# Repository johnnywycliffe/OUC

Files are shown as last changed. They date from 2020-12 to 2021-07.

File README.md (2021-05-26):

# Open Underglow Controller (OUC)
This project is designed to provide a better underglow control scheme than the one that comes with the LED strips. It has it's own controls, a small OLED screen, and a connector to the CANBUS for connecting to the car.

## Features
 - ESP 32 controller for fast LED updates
 - 256-bit colors for millions of colors
 - Configuarable patterns for uniqueness
 - Animations!
 - Brakes and turn signal controls for extended light modes
 - 4 12v channels to drive Underglow
 - 2 5v channels to drive extra underglow strips
 - CAN BUS connection to use LEDs as car gauges
 - Wifi/Bluetooth mode for phone control
 - Optional screen and joystick controls to bypass need for phone

## Hardware 
In this project are PCB files needed to order a board, parts files for having a board assembled, and 3d files for a 3d printing a case.

A full hardware list can be found in docs/hardware.md

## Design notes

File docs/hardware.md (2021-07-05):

# Hardware
Description of PCB and other hardware components needed 

## PCB Bill Of Materials
Prices are listed for 1 component as of 26MAY2021 from links provided

| Item Symbol | Part number | Usage | Quantity | Price (Unit) | Link |
| --- | --- | ----- | --- | --- | ---- |
| C1 | 100u (1210) | Decoupling | 1 | $0.19 | [Link](https://www.digikey.com/en/products/detail/cal-chip-electronics-inc/GMC32X5R107M6R3NT/12140448) |
| C2 | 1u (0402) | Decoupling | 1 | $<0.01 | [Link](https://www.digikey.com/en/products/detail/cal-chip-electronics-inc/GMC04X5R105K10NT/12324831) |
| C3, C4 | 2.2u (0603) | Decoupling | 2 | $<0.01 | [Link](https://www.digikey.com/en/products/detail/cal-chip-electronics-inc/GMC10X5R225K16NT/13908834) |
| C5 | 22n (0603) | Decoupling | 1 | $0.12 | [Link](https://www.digikey.com/en/products/detail/samsung-electro-mechanics/CL10B223KC8WPNC/11487758) |
| C6, C11, C12, C14 | 0.1u (0603) | Decoupling | 4 | $<0.01 | [Link](https://www.digikey.com/en/products/detail/cal-chip-electronics-inc/GMC10Y5V104Z16NTD/13907945) |
| C7, C8 | 47u (1210) | Decoupling | 2 | $<0.01 | [Link](https://www.digikey.com/en/products/detail/cal-chip-electronics-inc/GMC32X5R476M6R3NT/14288292) |
| C9, C10, C13, C15-20 | 10u (0603) | Decoupling | 9 | $0.02 | [Link](https://www.digikey.com/en/products/detail/cal-chip-electronics-inc/GMC10X5R106M6R3NT/13908308) |
| D1 | RB088BM-60TL | Reverse Polarity Protection | 1 | $1.01 | [Link](https://www.digikey.com/en/products/detail/rohm-semiconductor/RB088BM-60TL/13532505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) |
| D2 | TPSMA6L15A | TVS Diode | 1 | $0.43 | [Link](https://www.mouser.com/ProductDetail/Littelfuse/TPSMA6L15A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) |
| D3 | VSSAF512-M3/H | Switch mode power supply | 1 | $0.37 | [Link](https://www.mouser.com/ProductDetail/Vishay-General-Semiconductor/VSSAF512-M3-H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) |
| D4, D5 | TPSMB15A | CAN BUS ESD protection | 2 | $0.51 | [Link](https://www.mouser.com/ProductDetail/Littelfuse/TPSMB15A?qs=rXmh1mW8ce0d2DkAI15E9g%3D%3D) |
| D6 | B5818WS-F2-0000HF | USB reverse polarity protection | 1 | $0.03 | [Link](https://www.digikey.com/en/products/detail/yangzhou-yangjie-electronic-technology-co-ltd/B5818WS-F2-0000HF/13911526) |
| D7, D8 | 150040RS73240 | Indicator LEDs | 2 | $0.30 | [Link](https://www.digikey.com/en/products/detail/w%C3%BCrth-elektronik/150040RS73240/8557156) |
| F1 | 3413.0330.22 | Main fuse | 1 | $0.52 | [Link](https://www.digikey.com/en/products/detail/schurter-inc/3413-0330-22/2644179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) |
| J2 | 5063N17 | DB-9 connector for CANBUS | 1 | $2.08 | [Link](https://www.mcmaster.com/db9-connectors/computer-connection-type~db9/) |
| J3 | 47590-0001 | USB Connector | 1 | $0.74 | [Link](https://www.mouser.com/ProductDetail/Molex/47590-0001?qs=B2dI1vFk2x%252BDCUfk3sC4bA%3D%3D) |
| L1 | SRR1208-6R5ML | Inductor for Swich mode power supply | 1 | $1.01 | [Link](https://www.mouser.com/ProductDetail/Bourns/SRR1208-6R5ML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) |
| Q1, Q2 | SS8050-G | BJTs for boot mode | 2 | $0.26 | [Link](https://www.digikey.com/en/products/detail/comchip-technology/SS8050-G/6138901) |
| R1 | 49.9K (0603)  | Switch mode power supply | 1 | $<0.01 | [Link](https://www.digikey.com/en/products/detail/viking-tech/AR03DTC4992/12141691) |
| R2 | 100K (0603) | Switch mode power supply | 1 | $<0.01 | [Link](https://www.digikey.com/en/products/detail/viking-tech/CR-03FL7-100K/12141977) |
| R3 | 17.8K (0603) | Switch mode power supply | 1 | $<0.01 | [Link](https://www.digikey.com/en/products/detail/meritek/CR161782F/13405853) |
| R4, R5, R8, R10, R12, R14 | 10K (0603) | Various | 6 | $<0.01 | [Link](https://www.digikey.com/en/products/detail/viking-tech/CR-03FL7-10K/12141843) |
| R6 | 120 (0603) | CAN BUS Termination | 1 | $<0.01 | [Link](https://www.digikey.com/en/products/detail/meritek/CR16121J/13407570) |
| R7 | 4.7K (0603)  | USB Interface reset | 1 | $<0.01 | [Link](https://www.digikey.com/en/products/detail/meritek/CR16472J/13408047) |
| R9, R11, R13 | 27K (0603) | Voltage divider | 3 | $<0.01 | [Link](https://www.digikey.com/en/products/detail/meritek/CR16273J/13411248) |
| R15, R16 | 2.2k (0603) | LED Current limiting | 2 | $<0.01 | [Link](https://www.digikey.com/en/products/detail/meritek/CR16222J/13408118) |
| U1 | ESP-WROOM-32E (16MB) | Control device | 1 | $2.99 | [Link](https://www.mouser.com/ProductDetail/Espressif-Systems/ESP32-WROOM-32EM113EH2800PH3Q0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) |
| U2 | LMR14030-Q1 | 12-5v Switching regulator | 1 | $3.06 | [Link](https://www.mouser.com/ProductDetail/Texas-Instruments/LMR14030SQDDARQ1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) |
| U3 | NCP1117ST33T3G | 5-3.3v LDO | 1 | $0.56 | [Link](https://www.mouser.com/ProductDetail/ON-Semiconductor/NCP1117ST33T3G?qs=Gev%252BmEvV0iZb%2FE8ahUDx3w%3D%3D) |
| U4 | TXB0108DQSR | 3.3-5v Level shifter | 1 | $1.36 | [Link](https://www.digikey.com/en/products/detail/texas-instruments/TXB0108DQSR/2260592) |
| U5 | SN65HVD230 | CAN-bus Tranceiver | 1 | $3.00 | [Link](https://www.mouser.com/ProductDetail/Texas-Instruments/SN65HVD230QDRG4Q1?qs=pZC5fsuWujFPbC0sa1rjKA%3D%3D) |
| U6 | USBLC6-2SC6 | USB protection IC | 1 | $0.61 | [Link](https://www.mouser.com/ProductDetail/STMicroelectronics/USBLC6-2SC6?qs=po45yt2pPpu%2FhNIlwQdTlg%3D%3D) |
| U7 | CP2102N-A01-GQFN28 | USB Interface IC | 1 | $1.51 | [Link](https://www.mouser.com/ProductDetail/Silicon-Labs/CP2102N-A02-GQFN28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) |

## External electrical compentents
| Part name/number | Description | QTY | Price (unit) | Link |
| --- | --- | --- | ---| ---- |
| OBD2 Cable | Cable from OB2 Port of Car to device | 1 | $9.95 | [Link](https://www.digikey.com/catalog/en/partgroup/obd-ii-to-db9-cable/57744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,the%20cable%20is%20five%20feet.) |
| LEDS  WS2811, 12v | Some LEDs for test or install | 1 | $25.99 | [Link](https://www.amazon.com/BTF-LIGHTING-Addressable-Flexible-Silicone-Waterproof/dp/B01CNL6LLA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) |
| Joystick | Generic Joystick w/ pushbutton used for navigation of the menus | 1 | $1.00 | [Link](https://www.amazon.com/Wishiot-Joystick-Controller-Breakout-Arduino/dp/B089VXPHDH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) |
| OLED 0.96" | SSD1306, SPI screen for displaying information | 1 | $5.00 | [Link](https://www.amazon.com/CenryKay-0-96inch-Display-Compatible-Microcontroller/dp/B08238DZDL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) |
| Power interupt switch | Cut power to device to avoid draining battery | 1 | $5.79 | [Link](https://www.amazon.com/Baomain-Toggle-Switch-waterproof-cover/dp/B01IYD8SHQ) |
| Cable | Automotive grade cable with 3 cores | Varies | Varies | None |
| Cable connectors | Waterproof connectors, 5 core | 1-2 | $10.99 | [Link](https://www.amazon.com/gp/product/B01LCV8ZMA/ref=ppx_yo_dt_b_asin_title_o00_s00?ie=UTF8&psc=1)

## Case
TODO

## Pinout
Last verified on ver 1.3.2
| Item | Pin | Restrictions |
| ---- | --- | --- |
| LED SPARE 1 | 2 | No |
| LED Data (right) | 4 | No |
| LED Data (front) | 5 | No |
| OLED DC | 12 | No |
| OLED Reset | 14 | No |
| LED SPARE 2 | 15 | No |
| LED Data (rear) | 16 | No |
| LED Data (left) | 17 | No |
| OLED CLK | 18 | Hardware locked |
| SPI MISO | 19 | Hardware locked |
| Aux | 21 | Analog |
| Joystick Button | 22 | Needs internal pullup |
| SPI MOSI | 23 | Hardware locked |
| CAN TX | 25 | No |
| OLED CS | 26 | No |
| Brake Input | 32 | Input only | 
| CAN RX | 33 | No |
| Turn signal input Left | 34 | Input only |
| Turn Signal input Right | 35 | Input only | 
| Joystick X | 36 | Analog |
| Joystick Y | 39 | Analog |

## Notes
### Power
Vehicle power systems are generously described as "Hostile". So, there needs to be a system in place to get the power to everything. The voltage ranges from 11-14V and 10A typically, but there's spikes. Using a Trasient-Voltage-Suppression Diode, these problems are mitigatred.

12V is sent straight to LED strips via thick trace, an dimmediately regulated down to 5v, which is copper layer 3.

3.3v is moslty routed via layer 4, since it's spidering around the board.

### Misc
Screen D0 is CLK, D1 is MOSI.

Default QTY of Underglow LEDS is 18 for front and back, 30 for left and right.

Joystick is oriented with headers up.
- Y Axis pot is HIGH when DOWN, LOW when UP
- X Axis pot is HIGH when LEFT, LOW when RIGHT

May want to reorient for ease of mounting.

Pin 33 spazzes on software load.

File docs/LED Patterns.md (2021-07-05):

# LED Patterns
A list of patterns to implement.

Pixel order is clockwise, starting at front drivers corner front LED strip by default.

Use a pallette for storing colors. This allows for blending.

User defines up to four colors and the pallete adjusts for that

Special modes and effects are patterns, but don't utilize the data the same way.

Current test LEDS:
- Front/Back LED count is 18 pixels in groups of three
- Side LED count is 30 Pixels in groups of three.

## Math
To make sure the pattern loops around properly, move along length of palette like this:

paletteIndex = round(Current LED * (256/length of string))

This will minimized rounding error stackup. Example using pixel 55 of 96: 56 * 256/96 = 56 * 2.667 = 149.352 -> 149

Division is performed first to avoid overflowing.

## Patterns
Basic patterns, user programmable

1. 1 Wide: Two colors, odd pixels are color 1, evens color 2
2. 2 wide: every two pixels alternates color 1 and 2
3. 3 Wide: every three pixels...
4. 6 wide: every six pixels...
5. Dot(s) (with trail when animated)
6. Solid

## Animations
Can be applied to basic patterns

1. Cycle clockwise (Sawtooth?)
2. Cycle counterclockwise
3. Fade in and out
4. Fade in and out, alternating
5. Fade, random
6. Sinewave shift (Cylon)
7. Dot shift
8. Color pop - random color appears at random location. Spreads out until next pixel covers it up
9. Splatter - color(s) fades as it gets closer to back of vehicle
10. Drip - color(s) randomly, suddenly appears and fades

## Special patterns
Preset patterns, more complex than the "simple" patterns

1. Pacifica - Looks like water flowing 
2. Rising flames - Kind of like a candle
3. Twinklefox - Snow?
4. MURICA - Blue and white in the front, red and white down sides and rear. Flutters?
5. Valentine's - Pink, white and purple
6. Shamrock - Green shifting pattern
7. Halloween - Orange, green and purple
8. Christmas - Red and green lights, white twinkles
9. FFTss

## Colors
### Built in palettes
1. RainbowColors_p
2. RainbowStripeColors_p
3. OceanColors_p
4. CloudColors_p
5. LavaColors_p
6. ForestColors_p
7. PartyColors_p

### Pre-defined colors
1. Red
2. Green
3. Blue
4. White
5. Pink
6. Purple
8. Cyan
9. Yellow

More need added...

## Gauges
### Monochrome
1. Back to forwards (Front and back strips point inwards)
2. Forwards to back (Front and back strips point outwards)
3. Current gear (Brightness, color, or number of illuminated pixels)

### Multicolor
1. Back to forwards with "red" zone
2. Forwards to back with "red" zone
3. Layered gauges (Tracking two stats, overlaid)
4. Equalizer, with 'local maximum'

## Spare LEDs 1 & 2
These can either mimic the underglow, take only the primary color, or do something completely different.

## Turn signal and brake hardwires
### Brakes
1. Off
2. Off when not pressed, lit when pressed
3. Dim when not pressed, lit when pressed

### Turn signals
1. Off
2. Only sides of car, solid yellow
3. Sides of car in solid yellow, Outer front and rear LEDs flash yellow as well
4. Side of car in solid yellow, rear leds flash red on/off
5. Only sides of car, chasing yellow
6. Sides of car in chasing yellow, Outer front and rear LEDs flash yellow as well
7. Side of car in chasing yellow, rear leds flash red on/off

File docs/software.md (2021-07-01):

# Software
Software description and some constructs

## Overview
The general use of this device is to drive underglow LEDs based on a variety of inputs, with an extra few channels for additional LEDs should they be installed.

The inputs to the device are:
- OBD2/CANBUS: Direct information from the car. RPM, Throttle position, speed, gear, and anything else available.
- Self/Animations: Pre-programmed animations to drive LEDs in a set pattern.
- Turn Signals/Brakes: When installed, can light up red when braking and flash yellow when using turn signals

To choose between these, there is bluetooth mode or a joystick/button combo, or can be operated by computer

## Classes (make seperate libraries?)
- Menu: Handles operation ot he menu
  - Screen: Handles screen manipulation for menu class
  - Input: Handles joystick and button presses
  - Parser: Handles input from a serial device
    - Computer: Loads settings in ardiuno terminal when attached to a computer
    - Bluetooth: Loads data in when attached to bluetooth
- LEDPreset: Sets LEDs to be displayed
  - LEDPattern: Only contains data for an individual pattern
  - PatternManager: Actually updates patterns, inits them based on LEDPattern fed
  - LEDManager: Handles all hardware interface functions
- CAN: handle back and forth info to and from car
- EEPROM manager: Saving data to eeprom
- Settings: Settings stuff

## LED setup
- 5 presets saved to EEPROM, can be recalled at any time
- 1 Active preset; preset that will run when settings are finalized/aborted
- 1 preset for currently being modified patterns (called test)
- 1 LED manager
- 1 Pattern Manager

### Breakdown of LED operational theory
LEDManager:
- Has reference to real LEDs, all hardware driving functions
- Can call update function
- Shared between presets

LEDPreset:
- Generates pattern string with given preset
- Each preset has a pattern defined for each of the three strings: Underglow, Spare1 and Spare2
- These subpatterns are built into an overarching pattern which is loaded into LEDmanager

LEDPatterns:
- Where the current pattern is defined. Contains data like offset, length, brightness, palette...
- Does NOT contain LED array. Just information needed to construct array
- Probably could be a struct.

PatternManager:
- Given a LEDPattern, an offset and an Array to operate on, updates LEDs accordingly
- Shared between presets
- This class is going to setup and update the LEDs based on confiuration handed to it

## Menu
### Actives
- Load a new menu, resets sel and runs setupmenu(State)
- Load a new menu with a limited number of options
- Load a new menu with a custom title
- Save active pattern to test pattern
- Save test pattern to current pattern - abstract to two?
- Load a new menu and throw an eror for caution (Wiring, OBD-II, etc)
- Load a new menu and update selected LED string
- Save RGB order into hardware struct
- Save LED count into hardware struct
- Save LED flip state into hardware struct
- Save turn signal pattern into device settings
- Save brake pattern into device settings
- Save autoshutoff state into device settings
- Bluetooth

### Passives
- Update color palette on active: Active is known, state and sel describe 
- Update screen brightness: deviceSettings is known, 

# OUTDATED
Anything below this needs to be revised/removed

### Menu
The menu has a few modes:
- Navigation: consists of menu and submenues
- Choose color/pallete: Used to set colors
- Choose text: Used to set text (if needed)
- Choose PID: Choose a valid PID to monitor for gauges
- Variable adjust: Brightness, speed, anything represented as 1 number

LED patterns will continue to run while running settings.
- Custom patterns will change in real time for ease of modification
- Preset patterns will display when selecting them
- When choosing direction, indicate clockwise and have a slow clockwise pattern
- When choosing RGB, get initialization parameters and adjust accordingly. This may be difficult.
- When setting brakes and turn signals, provide a preview in real time

### OLED
A monochrome OLED display. Generic, used to display information about settings. 

### CAN/OBD2
The CAN/OBD2 libraries in use handle most of the packet send and receive pattern, only requiring a PID to get the relevant data in the correct units.

There are also helper functions to determine if a PID is valid, show units, and find all valid PIDs on a network.

### Input (Joystick)
Input is managed through a 2-axis joystick with 2 buttons. One of the buttons is part of the joystick.

### EEPROM
The EEPROM is used to store settings between power cycles.

There is a struct used to save and load all of the settings. It always writes the entire structure to the EEPROM, so limit number of times settings are saved. The struct uses put() and get() to avoid complicated byte management.

The same struct is what the rest of the program uses to get settings.

There is also a reset function.

### FastLED
See Patterns document for LED implementation.

## Settings
Some settings:
- Reverse direction of LED bar (For incorrect instals
- Set LED bar length
- Bluetooth on/of
- Bluetooth password (if possible)
- Blackout mode

## Bluetooth
Bluetooth integration can be done with no additional hardware, but will require a bunch of work on the software end, including a companion app for Android and iPhone.

Bluetooth works similarly to serial communication (read: it works identically from the ESP's perspective), but the messages have to be parsed on either end and displayed to the user in a sane manner. This is handled by the App for most bluetooth controllers on the market.

A standard for setting the LEDs needs to be made.

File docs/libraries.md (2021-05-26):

# Libraries
List of libraries used in the project and licenses needed to use them.

| Library Name | Author | Version | License | Link |
| --- | --- | --- | --- | ---- |
| Arduino-CAN | SandeepMistry | 0.3.1 | MIT | [Link](https://github.com/sandeepmistry/arduino-CAN) |
| Arduino-OBD2 | SandeepMistry | 0.0.0 | MIT | [Link](https://github.com/sandeepmistry/arduino-OBD2) |
| FastLED | Samguyer | 3.4.0 | MIT | [Link](https://github.com/FastLED/FastLED) |
| ESP 32 OLED | Thingpulse | 4.1.0 | MIT | [Link](https://github.com/ThingPulse/esp8266-oled-ssd1306) |
| Button | Michael Adams | 1.0.0 | MIT | [Link](https://github.com/madleech/Button) |

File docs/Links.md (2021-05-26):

# Links
## OBD2 info
[OBD2 explained](https://www.csselectronics.com/screen/page/simple-intro-obd2-explained/language/en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,that%20it%20can%20run%20on.)

[OBD2 PID list](https://en.wikipedia.org/wiki/OBD-II_PIDs)

[Send/receive info](https://happilyembedded.wordpress.com/2015/07/23/thirst-for-knowledge-sae-j1979-protocol/)

## ESP 32 info
[ESP 32 CAN (non-ardino)](http://www.iotsharing.com/2017/09/how-to-use-arduino-esp32-can-interface.html)

[ESP32 flash memory](https://www.electronics-lab.com/project/using-esp32s-flash-memory-for-data-storage/)

[ESP 32 based Logger board (for ref)](https://circuitmaker.com/Projects/Details/Craig-Peacock-4/OBD2-CAN-Logger)

[ESP 32 web portal](https://randomnerdtutorials.com/esp32-web-server-arduino-ide/)

[ESP 32 OBD2 Emulator](https://github.com/limiter121/esp32-obd2-emulator)

[Flash memory](https://randomnerdtutorials.com/esp32-flash-memory/)

[ESP WROOM 32 datasheet](https://www.espressif.com/sites/default/files/documentation/esp32-wroom-32e_esp32-wroom-32ue_datasheet_en.pdf)

[ESP32 Datasheet](https://www.espressif.com/sites/default/files/documentation/esp32_datasheet_en.pdf)

[ESP 32 Hardware design guidelines](https://www.espressif.com/sites/default/files/documentation/esp32_hardware_design_guidelines_en.pdf)

[ESP 32 Pinout](https://randomnerdtutorials.com/esp32-pinout-reference-gpios/)

## LEDS
[LED Library comparisons](https://blog.ja-ke.tech/2019/06/02/neopixel-performance.html)

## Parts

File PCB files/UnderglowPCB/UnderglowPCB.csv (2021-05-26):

Id | Designator | Quantity | Manufacturer | MFG Part # | Description/Value | Package | Type | Notes
1 | U1 | 1 | Espressif Systems | ESP32-WROOM-32E (M113EH2800PH3Q0) | Micrcontroller | ESP32-WROOM-32 | SMD
2 | D3 | 1 | Vishay General Semiconductor | VSSAF512-M3/H | Schottky diode | DO-221AC | SMD
3 | C1 | 1 | CAL-CHIP ELECTRONICS, INC. | GMC32X5R107M6R3NT | 100u | C_1210_3225Metric | SMD
4 | C12,C11,C14,C6 | 4 | CAL-CHIP ELECTRONICS, INC. | GMC10Y5V104Z16NTD | 0.1u | C_0603_1608Metric | SMD
5 | U4 | 1 | Texas Instruments | TXB0108DQSR | 3.3v to 5v Logic Level shifter | SON-20 | SMD
6 | U6 | 1 | Texas Instruments | SN65HVD230QDRG4Q1 | CAN-BUS Tranciever | SOIC-8 | SMD
7 | U8 | 1 | Sillicon Labs | CP2102N-A02-GQFN28 | USB to UART Bridge | QFN-28 | SMD
8 | D1 | 1 | ROHM Semiconductor | RB088BM-60TL | Schottky Protection diode | TO-252-2_TabPin1 | SMD
9 | C9,C17,C16,C15,C18,C19,C20,C13,C10 | 9 | CAL-CHIP ELECTRONICS, INC. | GMC10X5R106M6R3NT | 10u | C_0603_1608Metric | SMD
10 | D6 | 1 | Yangzhou Yangjie Electronic Technology Co.,Ltd | B5818WS-F2-0000HF | B5818WS | D_SOD-323 | SMD
11 | R7 | 1 | Meritek | CR16472J |  | R_0603_1608Metric | SMD
12 | U7 | 1 | STMicroelectronics | USBLC6-2SC6 | ESD Suppression | SOT-23-6 | SMD
13 | R8,R10,R12,R14,R4,R5 | 6 | Viking Tech | CR-03FL7---10K | 10k | R_0603_1608Metric | SMD
14 | J3 | 1 | Molex | 47590-0001 | USB_B_Micro | USB_Micro-AB_Molex_47590-0001 | Thru-hole
15 | F1 | 1 | Schurter Inc | 3413.0330.22 | Fuse | Fuse_1206_3216Metric | SMD
16 | U3 | 1 | ON Semiconductor | NCP1117ST33T3G | 3.3V Regulator | SOT-223-3_TabPin2 | SMD
17 | R9,R11,R13 | 3 | Meritek | CR16273J | 27k | R_0603_1608Metric | SMD
18 | R6 | 1 | Meritek | CR16121J | 120 | R_0603_1608Metric | SMD
19 | Q1,Q2 | 2 | Comchip Technology | SS8050-G | NPN Transistor | SOT-23 | SMD
20 | C2 | 1 | CAL-CHIP ELECTRONICS, INC. | GMC04X5R105K10NT | 1u | C_0402_1005Metric | SMD
21 | D7,D8 | 2 | Würth Elektronik | 150040RS73240 | LED | LED_0603_1608Metric | SMD
22 | R15,R16 | 2 | Meritek | CR16222J |  | R_0603_1608Metric | SMD
23 | C3,C4 | 2 | CAL-CHIP ELECTRONICS, INC. | GMC10X5R225K16NT | 2.2u | C_0603_1608Metric | SMD
24 | C5 | 1 | Samsung Electro-Mechanics | CL10B223KC8WPNC | 22n | C_0603_1608Metric | SMD
25 | C7,C8 | 2 | CAL-CHIP ELECTRONICS, INC. | GMC32X5R476M6R3NT | 47u | C_1210_3225Metric | SMD
26 | D2 | 1 | Littelfuse | TPSMA6L15A | TVS Diode | DO-221AC-2 (SMA) | SMD
27 | D4,D5 | 2 | Littelfuse | TPSMB15A | TPSMB15CA | DO-214AA-2 | SMD
28 | L1 | 1 | Bourns | SRR1208-6R5ML | 6.5u | Non-standard | SMD
29 | R1 | 1 | Viking Tech | AR03DTC4992 | 49.9k | R_0603_1608Metric | SMD
30 | R2 | 1 | Viking Tech | CR-03FL7--100K | 100k | R_0603_1608Metric | SMD
31 | R3 | 1 | Meritek | CR161782F | 17.8k | R_0603_1608Metric | SMD
32 | U2 | 1 | Texas Instruments | LMR14030SQDDARQ1 | 12v Switch mode power supply | 8-PowerSOIC (0.154", 3.90mm Width) | SMD
33 | J8,J9,J10,J4,J5,J6,J7,J1 | 8 |  |  | Conn_01x03 | PinHeader_1x03_P2.54mm_Vertical |  | DNS/DNP/DNI
34 | J11 | 1 |  |  | Conn_01x05 | Joystick_Header |  | DNS/DNP/DNI
35 | J12 | 1 |  |  | Conn_01x07 | SSD1306_Footprint |  | DNS/DNP/DNI
36 | J2 | 1 |  |  | DB9_Male | DB9 |  | DNS/DNP/DNI

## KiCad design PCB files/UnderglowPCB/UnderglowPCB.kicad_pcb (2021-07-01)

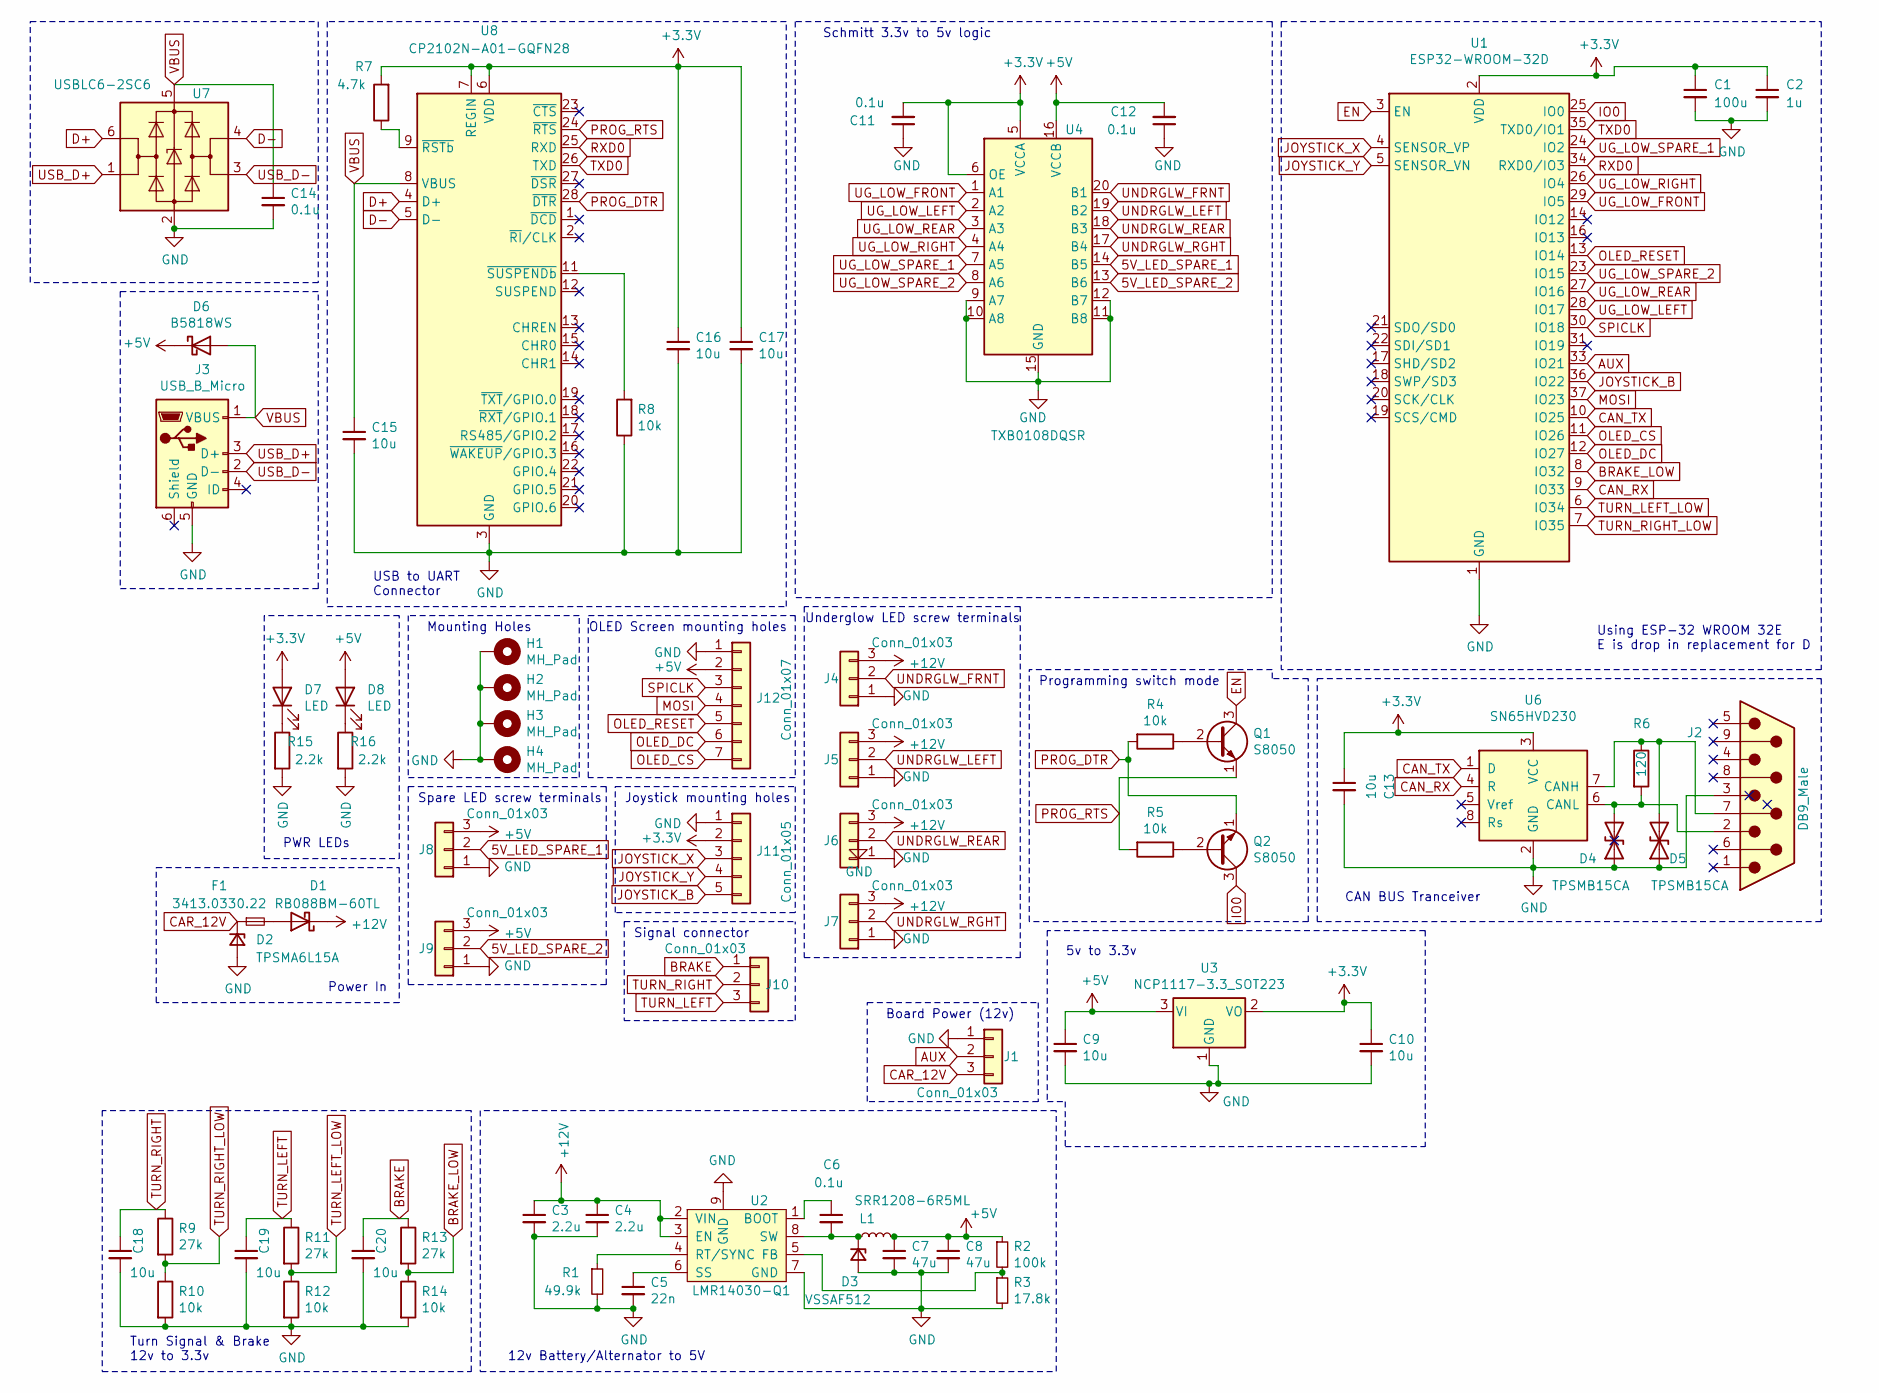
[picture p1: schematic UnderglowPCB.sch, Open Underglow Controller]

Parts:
C1: 100u; C_1210_3225Metric
C2: 1u; C_0402_1005Metric
C3, C4: 2.2u; C_0603_1608Metric
C5: 22n; C_0603_1608Metric
C6, C11, C12, C14: 0.1u; C_0603_1608Metric
C7, C8: 47u; C_1210_3225Metric
C9, C10, C13, C15, C16, C17, C18, C19, C20: 10u; C_0603_1608Metric
D1: RB088BM-60TL; TO-252-2_TabPin1
D2: TPSMA6L15A
D3: VSSAF512; DO-221AC
D4, D5: TPSMB15CA
D6: B5818WS; D_SOD-323
D7, D8: LED; LED_0603_1608Metric
F1: 3413.0330.22; Fuse_1206_3216Metric
H1, H2, H3, H4: MH_Pad; MountingHole_4.3mm_M4_Pad_Via
J1, J4, J5, J6, J7, J8, J9, J10: Conn_01x03; PinHeader_1x03_P2.54mm_Vertical
J2: DB9_Male; DB9
J3: USB_B_Micro; USB_Micro-AB_Molex_47590-0001
J11: Conn_01x05; Joystick_Header
J12: Conn_01x07; SSD1306_Footprint
L1: SRR1208-6R5ML; SRR1208
Q1, Q2: S8050; SOT-23
R1: 49.9k; R_0603_1608Metric
R2: 100k; R_0603_1608Metric
R3: 17.8k; R_0603_1608Metric
R4, R5, R8, R10, R12, R14: 10k; R_0603_1608Metric
R6: 120; R_0603_1608Metric
R7: 4.7k; R_0603_1608Metric
R9, R11, R13: 27k; R_0603_1608Metric
R15, R16: 2.2k; R_0603_1608Metric
U1: ESP32-WROOM-32D; ESP32-WROOM-32
U2: LMR14030-Q1; Texas_HSOP-8-1EP_3.9x4.9mm_P1.27mm_ThermalVias
U3: NCP1117-3.3_SOT223; SOT-223-3_TabPin2
U4: TXB0108DQSR; USON-20_2x4mm_P0.4mm
U6: SN65HVD230; Texas_HSOP-8-1EP_3.9x4.9mm_P1.27mm_ThermalVias
U7: USBLC6-2SC6; SOT-23-6
U8: CP2102N-A01-GQFN28; QFN-28-1EP_5x5mm_P0.5mm_EP3.35x3.35mm

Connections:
5V_LED_SPARE_1: J8.2, U4.14 (B5)
5V_LED_SPARE_2: J9.2, U4.13 (B6)
+3V3: C1.1, C2.1, C10.1, C11.2, C13.1, C16.1, C17.1, D7.2 (A), J11.2, R7.2, U1.2 (VDD), U3.2 (VO), U4.5 (VCCA), U4.6 (OE), U6.3 (VCC), U8.6 (VDD), U8.7 (REGIN)
+5V: C7.1, C8.1, C9.1, C12.2, D6.1 (K), D8.2 (A), J8.3, J9.3, J12.2, L1.2, R2.1, U3.3 (VI), U4.16 (VCCB)
+12V: C3.1, C4.1, D1.1 (K), J4.3, J5.3, J6.3, J7.3, U2.2 (VIN), U2.3 (EN)
AUX: J1.2, U1.33 (IO21)
BRAKE: C20.1, J10.1, R13.1
BRAKE_LOW: R13.2, R14.1, U1.8 (IO32)
CAN_RX: U1.9 (IO33), U6.4 (R)
CAN_TX: U1.10 (IO25), U6.1 (D)
CAR_12V: D2.1 (K), F1.1, J1.3
D+: U7.6 (I/O1), U8.4 (D+)
D-: U7.4 (I/O2), U8.5 (D-)
EN: Q1.3 (C), U1.3 (EN)
GND: C1.2, C2.2, C3.2, C4.2, C5.2, C7.2, C8.2, C9.2, C10.2, C11.1, C12.1, C13.2, C14.2, C15.2, C16.2, C17.2, C18.2, C19.2, C20.2, D2.2 (A), D3.2 (A), D4.1 (A1), D5.1 (A1), H1.1, H2.1, H3.1, H4.1, J1.1, J2.3, J3.5 (GND), J4.1, J5.1, J6.1, J7.1, J8.1, J9.1, J11.1, J12.1, R1.2, R3.2, R8.1, R10.2, R12.2, R14.2, R15.2, R16.2, U1.1 (GND), U1.15 (GND), U1.38 (GND), U1.39 (GND), U2.7 (GND), U2.9 (GND), U3.1 (GND), U4.9 (A7), U4.10 (A8), U4.11 (B8), U4.12 (B7), U4.15 (GND), U6.2 (GND), U7.2 (GND), U8.3 (GND), U8.29 (GND)
IO0: Q2.3 (C), U1.25 (IO0)
JOYSTICK_B: J11.5, U1.36 (IO22)
JOYSTICK_X: J11.3, U1.4 (SENSOR_VP)
JOYSTICK_Y: J11.4, U1.5 (SENSOR_VN)
MOSI: J12.4, U1.37 (IO23)
unnamed: C5.1, U2.6 (SS)
unnamed: C6.1, U2.1 (BOOT)
unnamed: C6.2, D3.1 (K), L1.1, U2.8 (SW)
unnamed: D1.2 (A), F1.2
unnamed: D4.2 (A2), J2.2, R6.2, U6.6 (CANL)
unnamed: D5.2 (A2), J2.7, R6.1, U6.7 (CANH)
unnamed: D7.1 (K), R15.1
unnamed: D8.1 (K), R16.1
unnamed: Q1.2 (B), R4.1
unnamed: Q2.2 (B), R5.1
unnamed: R1.1, U2.4 (RT/SYNC)
unnamed: R2.2, R3.1, U2.5 (FB)
unnamed: R7.1, U8.9 (~RSTb)
unnamed: R8.2, U8.11 (~SUSPENDb)
OLED_CS: J12.7, U1.11 (IO26)
OLED_DC: J12.6, U1.12 (IO27)
OLED_RESET: J12.5, U1.13 (IO14)
PROG_DTR: Q2.1 (E), R4.2, U8.28 (~DTR)
PROG_RTS: Q1.1 (E), R5.2, U8.24 (~RTS)
RXD0: U1.34 (RXD0/IO3), U8.25 (RXD)
SPICLK: J12.3, U1.30 (IO18)
TURN_LEFT: C19.1, J10.3, R11.1
TURN_LEFT_LOW: R11.2, R12.1, U1.6 (IO34)
TURN_RIGHT: C18.1, J10.2, R9.1
TURN_RIGHT_LOW: R9.2, R10.1, U1.7 (IO35)
TXD0: U1.35 (TXD0/IO1), U8.26 (TXD)
UG_LOW_FRONT: U1.29 (IO5), U4.1 (A1)
UG_LOW_LEFT: U1.28 (IO17), U4.2 (A2)
UG_LOW_REAR: U1.27 (IO16), U4.3 (A3)
UG_LOW_RIGHT: U1.26 (IO4), U4.4 (A4)
UG_LOW_SPARE_1: U1.24 (IO2), U4.7 (A5)
UG_LOW_SPARE_2: U1.23 (IO15), U4.8 (A6)
UNDRGLW_FRNT: J4.2, U4.20 (B1)
UNDRGLW_LEFT: J5.2, U4.19 (B2)
UNDRGLW_REAR: J6.2, U4.18 (B3)
UNDRGLW_RGHT: J7.2, U4.17 (B4)
USB_D+: J3.3 (D+), U7.1 (I/O1)
USB_D-: J3.2 (D-), U7.3 (I/O2)
VBUS: C14.1, C15.1, D6.2 (A), J3.1 (VBUS), U7.5 (VBUS), U8.8 (VBUS)

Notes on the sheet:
12v Battery/Alternator to 5V
Underglow LED screw terminals
Spare LED screw terminals
Using ESP-32 WROOM 32E E is drop in replacement for D
Joystick mounting holes
CAN BUS Tranceiver
OLED Screen mounting holes
Signal connector
USB to UART Connector
Schmitt 3.3v to 5v logic
Turn Signal & Brake 12v to 3.3v
PWR LEDs
5v to 3.3v
Programming switch mode
Board Power (12v)
Mounting Holes
Power In

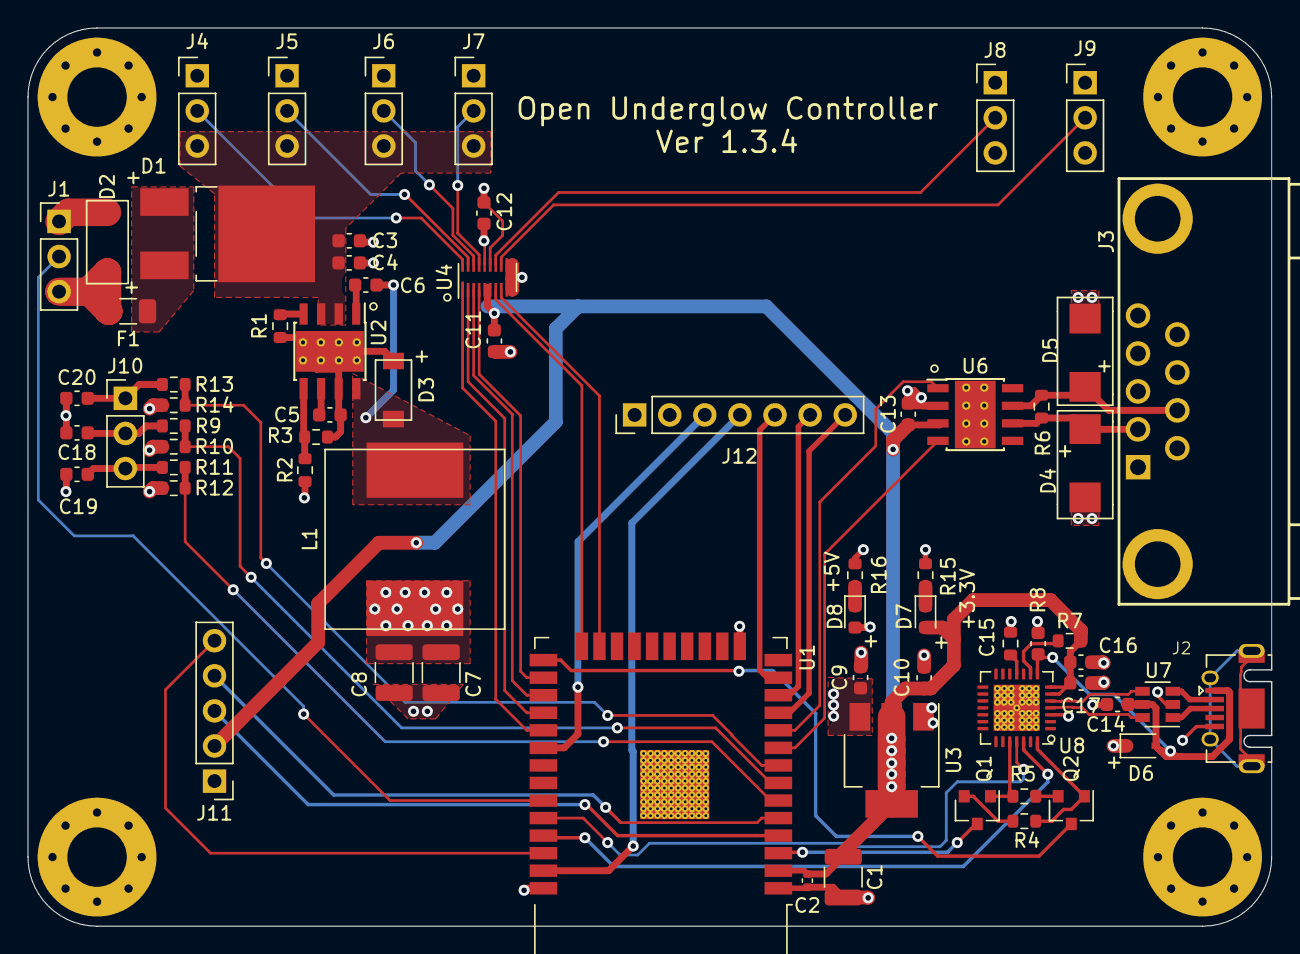
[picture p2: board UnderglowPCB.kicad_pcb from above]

Board: 4 copper layers, 90.0 x 65.0 mm, 71 parts (0 on the bottom side), 59 nets.

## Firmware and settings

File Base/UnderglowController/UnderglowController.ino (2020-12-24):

// UnderglowController.ino
// Copyright (c) 2020 Jeremy Stintzcum, all rights reserved.
// License: MIT
// Description: A controller for underglow/LED strips. Designed to grab infor frm a vehicle
// through ODB-II port, display a preset or custom pattern, or act as additional turn signals 
// or brake lights.

//=============================================================================================
// TODO (rough order of priority):
// Non-submenu functionality / options
// - Add in menu for Spare 1 and Spare 2
// - Remove LED type menu items. 
// LEDHardware settings adjustment
// LED setters
// LED preset modes
// Brake/Turn signal modes
// Bluetooth
// App (Android)
// Chain between vehicles

/*=============================================================================================
 * LED pattern - default (Can be changed in settings)
 *      18                          32|33                           47
 *       |                            V                             |
 *       # # # # # # # # # # # # # # # # # # # # # # # # # # # # # #
 * 17 > #                                                           # < 48
 *      #                         PASSENGER                         #
 *      #                                                           #
 *      #     LEDs are represented a "#"                            #
 *      #                                                           #
 *      #                                                           #
 *      # F   0 is driver corner of car                             #
 *      # R                                                      R  #
 *  9 > # O                                                      E  # < 56
 *  8 > # N   Numbers are positioned along string                A  # < 57
 *      # T                                                      R  #
 *      #                                                           #
 *      #     Long sides are 30 LEDS long                           #
 *      #                                                           #
 *      #                                                           #
 *      #     Short sides are 18 LEDS long                          #
 *      #                                                           #
 *  0 > #                         DRIVER                            # < 65
 *       # # # # # # # # # # # # # # # # # # # # # # # # # # # # # #
 *       |                          ^                              |
 *      95                        81|80                            66
 */
 
//Libraries
#include <EEPROM.h>
#include <CAN.h>
#include <OBD2.h>
#include "SSD1306Spi.h"
#include <FastLED.h>
#include <Button.h>

//Defines
#define EEPROM_SIZE 8 //Adjust based on actual need (Get sizeof settings struct)
#define RETRY_SPEED 1000 //In milliseconds, higher is slower
#define DEADZONELOW 300
#define DEADZONEHIGH 3896
#define MAX_BRIGHTNESS 200
//Input
#define UP 0
#define DOWN 1
#define LEFT 2
#define RIGHT 3
#define SELECT 4
#define BACK 5
//Hardware pins - ESP32 defined
#define SPI_MOSI 23 
#define SPI_MISO 19
#define SPI_CLK 18
//Pins - Display
#define DISP_RESET 5
#define DISP_CS 4
#define DISP_DC 2
//Pins - input
#define JOYSTICK_X 32
#define JOYSTICK_Y 33
#define JOYSTICK_BUTTON 21
#define BUTTON_0 22
//Pins - LED outputs
#define LED_FRONT 26
#define LED_REAR 27
#define LED_LEFT 13
#define LED_RIGHT 25
#define LED_SPARE1 15
#define LED_SPARE2 14
//Pins - Input signals
#define LTURNSIGNAL 22
#define RTURNSIGNAL 21
#define BRAKE 16
#define CANH 36
#define CANL 39
//Pins - other
#define RELAY 12

//Globals/enums
//Menu
enum State{
  main, settings, gauge1, pattern1, pattern2, pattern3, bluetooth, ledsetting1, ledsetting2,
  brakeandturn, brake, turn, color, pickpattern, animation, ledorder
};
int sel = 0; //current selection
bool demo = false; //if true, lets user preview LEDS as they scroll through options
bool screenUpdated = false; //Updates screen if true
//LEDs
enum ColorOrder {
  rgb, rbg, grb, gbr, brg, bgr
};
enum SelectedPattern {
  narrow, medium, large, wide, halfandhalf, quarters, dots, pacifica, risingflames, twinklefox,
  murica, colorpop, splatter, drip, christmas, valentines, shamrock, halloween
};
enum SelectedString {
  front, rear, passenger, driver, spare1, spare2
};
bool preset = false; //TODO: move to EERPOM saved settings

//Structs/Classes
// Lighting system struct
typedef struct {
  uint8_t offsetPos; //How offset from default position pattern is.
  CRGBPalette16 RGBP; //RGB color pallette
  uint8_t brightness; //Brightness level of LEDs
  uint8_t animSpd; //Animation speed
  uint8_t trackedPID; // OBD-II PID Datsa to be read (if relevant)
  SelectedPattern sp; //Current pattern used
} LEDPatterns;

// Hardware definition struct
typedef struct {
  bool reversed = true; //True for backwards, false for forwards
  uint8_t ledCount; //num of LEDs on strip.
  int startPos; //First led array val
  ColorOrder order; //BRG for test code
} LEDHardware;

// Settings struct for running program.
typedef struct{
  //Holds setting data to be written to EEPROM
  //ADMIN:
  char deviceID[10]; //Custom ID for ease of connection
  bool AllowSerial;
  //LED hardware
  
  //Light patterns
  LEDPatterns curr;
  LEDPatterns preset1;
  LEDPatterns preset2;
  LEDPatterns preset3;
  LEDPatterns preset4;
  LEDPatterns preset5;
  //User settings
  bool Bluetooth; //Bluetooth on or off
  bool rollingShutoff; //If device should cut power when vehicle in motion
  bool blinkersAndBrakes; //Mimics blinkers and brakes when driving
} Settings;

// MenuItem Struc for objects
typedef struct{
  char *title; //Title text
  char *desc; //Description text
  int8_t pid; //For storing PIDs
} MenuItem;

// Menu class
class Menu{
  MenuItem itemArr[100];
  int8_t len;
  char *menuTitle;
  State s;
  State prev;
public:
  Menu(){
    len = 0;
  }
  ~Menu(){
    delete itemArr;
  }
  //Set
  void setState(State state){
    s = state;
  }
  void resetLen(){
    len = 0;
  }
  void setItem(char *t, char *d, int8_t PID = 0){
    itemArr[len].title = t;
    itemArr[len].desc = d;
    itemArr[len].pid = PID;
    len++;
  }
  void setMenuTitle(char *mt){
    menuTitle = mt;
  }
  void setPrevMenu(State s){
    prev = s;
  }
  //Get
  int8_t getLen(){
    return len;
  }
  char* getMenuTitle(){
    return menuTitle;
  }
  char* getTitle(int pos){
    return itemArr[pos].title;
  }
  char* getDesc(int pos){
    return itemArr[pos].desc;
  }
  int8_t getPID(int pos){
    return itemArr[pos].pid;
  }
  State getState(){
    return s;
  }
  State getPrevMenu(){
    return prev;
  }
};

//Initialization
SSD1306Spi display(DISP_RESET, DISP_DC, DISP_CS);
Settings settingStruct;
Button joyButton(JOYSTICK_BUTTON, PULLUP);
Button button1(BUTTON_0, PULLUP);
CRGB *underglow;

Menu mMenu;
State s;
LEDPatterns active;
SelectedString sLEDString;
LEDHardware frontLH;
LEDHardware rightLH;
LEDHardware rearLH;
LEDHardware leftLH;
LEDHardware spare1LH;
LEDHardware spare2LH;

void setup() {
  // Set up each system
  EEPROM.begin(EEPROM_SIZE);
  // Display
  display.init();
  display.flipScreenVertically();
  display.setContrast(255);
  // Controls
  joyButton.begin();
  button1.begin();
  // LEDs
  setupLEDs();
  // OBD2
  /*while(!OBD2.begin()){
    //Ask user to check connection to vehicle, pause for a second
    delay(RETRY_SPEED);
  }*/
  //Menu
  setupMenu(main);
  // load settings
  loadSetting();
}

void loop() {
  // Bluetooth input
  // Menu - Change to only be active when needed
  int result = menuSelect(&mMenu, sel);
  //Return to main menu
  if(result==-1){
    sel = 0;
    if(s != main){
      setupMenu(mMenu.getPrevMenu());
    } 
  }
  //Behaviours for menu states
  switch(s){
    default:
      //Do nothing
      break;
  }
  //Refresh rate (Faster allows for more inputs, but thumbstick will scroll rapidly)
  delay(150);
}

//Set menu options and prepare for display
void setupMenu(State sel){
  mMenu.resetLen();
  mMenu.setState(sel);
  switch(sel){
    default: //If a menu hasn't been implemented or an error occurs, return to main
      pError("Not defined, returning to main");
    case main: //Default menu
      mMenu.setMenuTitle("Main Menu");
      mMenu.setPrevMenu(main);
      mMenu.setItem("Display","Display current selection");
      mMenu.setItem("Gauges","Choose a Gauge");
      mMenu.setItem("Animations","Choose an LED Animation");
      mMenu.setItem("Settings","Display current settings");
      break;
    case gauge1: //Top level gauge menu
      mMenu.setMenuTitle("");
      mMenu.setPrevMenu(main);
      mMenu.setItem("","");
      break;
    case pattern1: //Top level pattern menu
      mMenu.setMenuTitle("Pattern selection");
      mMenu.setPrevMenu(main);
      mMenu.setItem("Custom pattern","Choose colors, pattern and animations");
      mMenu.setItem("Preset patterns","A selection of pre-made patterns");
      break;
    case pattern2: //Custom patterns menu
      mMenu.setMenuTitle("Custom patterns");
      mMenu.setPrevMenu(pattern1);
      mMenu.setItem("Set Pattern","Choose specific pattern to display");
      mMenu.setItem("Set Colors","Choose colors for display");
      mMenu.setItem("Set Animation","Choose animation to display");
      break;
    case pickpattern: //Choose a pattern + offset
      mMenu.setMenuTitle("Pattern Selection");
      mMenu.setPrevMenu(pattern2);
      mMenu.setItem("Narrow","1 pixels wide");
      mMenu.setItem("Medium","2 pixels wide");
      mMenu.setItem("Large","3 pixels wide");
      mMenu.setItem("Wide","6 pixels wide");
      mMenu.setItem("Half-n-Half","2 colors");
      mMenu.setItem("Quarters","4 colors");
      mMenu.setItem("Dots","Includes trail");
      break;
    case color: //Pick a method of choosing color (Next level down, include fade or no fade options)
      mMenu.setMenuTitle("Color selection");
      //TODO: Set prev menus from calling menu
      mMenu.setItem("Standard colors","A list of common colors");
      mMenu.setItem("Pallete","Pick from a pre-made pallete");
      mMenu.setItem("RGB","Pick values by RGB values");
      mMenu.setItem("HSV","Pick values by HSV method");
      break;
    case animation: //Choose animation + Animation speed
      mMenu.setMenuTitle("Animation Selection");
      mMenu.setPrevMenu(pattern2);
      mMenu.setItem("Cycle CW","Cycles pattern clockwise");
      mMenu.setItem("Cycle CCW","Cycles pattern counterclockwise");
      mMenu.setItem("Breathe","LEDs fade in and out all at once");
      mMenu.setItem("Fade","LEDs alternate fading in and out");
      mMenu.setItem("Random Fade","LEDs fade randomly");
      mMenu.setItem("Cylon","Back and forth");
      mMenu.setItem("Color pop","Sparks of color");
      mMenu.setItem("Splatter","Like plowing through somethign");
      mMenu.setItem("Drip","Color dripping from under car");
      break;
    case pattern3: //Premade patterns menu
      mMenu.setMenuTitle("Premade patterns");
      mMenu.setPrevMenu(pattern1);
      mMenu.setItem("Pacifica","A calming water effect");
      mMenu.setItem("Rising Flames","A not-so-calming flame effect");
      mMenu.setItem("TwinkleFox","I got nothin'");
      mMenu.setItem("MURICA","FREEDOM MODE");
      mMenu.setItem("Valentines","Think fluffy thoughts");
      mMenu.setItem("Shamrock","Top o' the mornin'");
      mMenu.setItem("Halloween","Spooky");
      mMenu.setItem("Christmas","Commercialization!");
      break;
    case settings: //Main settings menu
      mMenu.setMenuTitle("Settings");
      mMenu.setPrevMenu(main);
      mMenu.setItem("LED Settings","Set up and tweak LEDs");
      mMenu.setItem("Brake and Turn","Brake and turn signal wiring");
      mMenu.setItem("Bluetooth","Set up bluetooth");
      mMenu.setItem("Driving shutoff","Automatically cut lights when car in motion");
      mMenu.setItem("Device Info","Licenses, credits, stuff like that");
      break;
    case ledsetting1: //Pick which LED string is being accessed.
      mMenu.setMenuTitle("Set up LED string.");
      mMenu.setPrevMenu(settings);
      mMenu.setItem("Front string","Direction, number, etc.");
      mMenu.setItem("Passenger string","Direction, number, etc.");
      mMenu.setItem("Rear string","Direction, number, etc.");
      mMenu.setItem("Driver string","Direction, number, etc.");
      mMenu.setItem("Spare string 1","Direction, number, etc.");
      mMenu.setItem("Spare string 2","Direction, number, etc.");
      break;
    case ledsetting2:
      //TODO: Change title based on LED string selected
      mMenu.setPrevMenu(ledsetting1);
      mMenu.setItem("Color order","Change RGB color order"); //Default for WS2811s is GRB
      mMenu.setItem("Number","Change number of LEDs on the strip"); //Remember to put notice for WS2811s
      mMenu.setItem("Direction","Change direction of led flow"); //Reverse strip if installed backwards
      break;
    case ledorder: //Top level gauge menu
      mMenu.setMenuTitle("Select color Order");
      mMenu.setPrevMenu(ledsetting2);
      mMenu.setItem("RGB","Should display red, green, blue");
      mMenu.setItem("RBG","Should display red, green, blue");
      mMenu.setItem("GRB","Should display red, green, blue");
      mMenu.setItem("GBR","Should display red, green, blue");
      mMenu.setItem("BRG","Should display red, green, blue");
      mMenu.setItem("BGR","Should display red, green, blue");
      break;
    case brakeandturn: //Set brake and turn signal behavior
      mMenu.setMenuTitle("Brakes and signals");
      mMenu.setPrevMenu(settings);
      mMenu.setItem("Brakes","Set brake behavior");
      mMenu.setItem("Turn signals","Set turn signal behavior");
      break;
    case bluetooth: //Bluetooth settings
      mMenu.setMenuTitle("Bluetooth settings");
      mMenu.setPrevMenu(settings);
      mMenu.setItem("BT Enabled","Toggle bluttooth on or off.");
      mMenu.setItem("BT Name","Name for identifying device.");
      mMenu.setItem("BT Pair","Pair a new bluetooth device.");
      break;
  }
  ShowMenu(&mMenu, sel);
}

//Navigate menus
int menuSelect(Menu *m, int &select){
  //Get input
  int8_t input = getInput();
  switch(input){
    case UP:
      select--;
     //Wrap if out of bounds
      if(select < 0){
        select = m->getLen()-1;
      }
      break;
    case DOWN:
      select++;
      //Wrap if out of bounds
      if(select >= m->getLen()){
        select = 0; 
      }
      break;
    case LEFT:
    case BACK:
      //exit back to parent menu
      return -1;
      break;
    case RIGHT:
    case SELECT:
      //Send state to execution table for further input
      return executionTable(m->getState(),select);
      break;
  }
  Serial.println(select);
  return 0;
}

//Displays menu item
void ShowMenu(Menu *m, int select){
  display.clear();
  display.setFont(ArialMT_Plain_16);
  display.setTextAlignment(TEXT_ALIGN_LEFT);
  display.drawStringMaxWidth(0,12,128,m->getTitle(select));
  display.setFont(ArialMT_Plain_10);
  display.drawStringMaxWidth(0,28,128,m->getDesc(select));
  display.display();
}
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

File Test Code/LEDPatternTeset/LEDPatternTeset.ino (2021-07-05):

#include <FastLED.h>
/*=============================================================================================
 * LED pattern - default (Can be changed in settings)
 *      18                          32|33                           47
 *       |                            V                             |
 *       # # # # # # # # # # # # # # # # # # # # # # # # # # # # # #
 * 17 > #                                                           # < 48
 *      #                         PASSENGER                         #
 *      #                                                           #
 *      #     LEDs are represented a "#"                            #
 *      #                                                           #
 *      #                                                           #
 *      # F   0 is driver corner of car                             #
 *      # R                                                      R  #
 *  9 > # O                                                      E  # < 56
 *  8 > # N   Numbers are positioned along string                A  # < 57
 *      # T                                                      R  #
 *      #                                                           #
 *      #     Long sides are 30 LEDS long                           #
 *      #                                                           #
 *      #                                                           #
 *      #     Short sides are 18 LEDS long                          #
 *      #                                                           #
 *  0 > #                         DRIVER                            # < 65
 *       # # # # # # # # # # # # # # # # # # # # # # # # # # # # # #
 *       |                          ^                              |
 *      95                        81|80                            66
 */

//Defines
#define FRONT_LED_PIN 5
#define RIGHT_LED_PIN 4
#define LEFT_LED_PIN 17
#define REAR_LED_PIN 16
#define SPARE1_LED_PIN 2
#define SPARE2_LED_PIN 15

//TODO: Move these to a global type scope for ease of use
//Declarations
enum ColorOrder { //LED color orders
  rgb, rbg, grb, gbr, brg, bgr
};

enum Pattern {
  solid, narrow, medium, large, wide, dots, 
  animation //Animation is used only for items that don't allow a preset arrangement of pixels
};

enum Animation {
  staticLEDs, rotateCW, rotateCCW, fade1, fade2, faderand, cylon,     //Uses pattern
  colorpop, splatter, drip,                                           //Uses pattern, but needs special setup
  pacifica, flames, murica, valntine, shamrock, halloween, christmas, //Uses pattern, but needs psecial setup
  gauge1, gauge2, gauge3, gauge4, gauge5, gauge6, gauge7,             //Gauge clusters
  brakes1, brakes2, brakes3, signal1, signal2, signal3, signal4, signal5, signal6 //Car exclusive
};

//TODO: refactor to not be entirely public
class LEDString {         //Individual strings of LEDs
public:
  bool reversed = false;  //If LED strip is reversed.
  uint8_t ledCount;       //Number of LEDs on this strip
  int startPos;           //Position in main array
  ColorOrder cOrder;      //Order of LEDs
  //Member functions
  void setLEDStripData(uint8_t, ColorOrder, bool);
};

//Initialize indiivdual LED string
void LEDString::setLEDStripData(uint8_t lCount, ColorOrder cO=rgb, bool rev=false){
  ledCount = lCount;
  cOrder = cO;
  reversed = rev;
}

//LED manager need sot contain all the of the LED control code
class LEDManager {              
  //Members
  LEDString frontLED;
  LEDString rightLED;
  LEDString rearLED;
  LEDString leftLED;
  LEDString spare1LED;
  LEDString spare2LED;
  CRGB *ledArr;                 //Main FastLED class
  int totalLEDs;                //Number of total LEDS
  //Private functions
  void setupLEDs();             //Function to run to instantiate LEDs in memory
  void colorSorter(CRGB,int);
public:
  void initLEDs(uint8_t*,ColorOrder*,bool*);  //Function settings are passed to to set up for initialization
  void updateLEDs(CRGB*);                          //Updates all LEDs in system
  LEDString* generateConfig();                //Returns a list of data to store
  //Getters
  int getTotalLength(){return totalLEDs;}
  int getUnderglowLength();
  int getSpare1Length(){return spare1LED.ledCount;}
  int getSpare2Length(){return spare2LED.ledCount;}
  CRGB* getLEDArr(){return ledArr;}
};

//LED Initialization
//Initialized LEDs to be set up.
void LEDManager::initLEDs(uint8_t *lCounts, ColorOrder *cOs, bool *rev){
  //Load data into strips
  frontLED.setLEDStripData(lCounts[0],cOs[0],rev[0]);
  rightLED.setLEDStripData(lCounts[1],cOs[1],rev[1]);
  rearLED.setLEDStripData(lCounts[2],cOs[2],rev[2]);
  leftLED.setLEDStripData(lCounts[3],cOs[3],rev[3]);
  spare1LED.setLEDStripData(lCounts[4],cOs[4],rev[4]);
  spare2LED.setLEDStripData(lCounts[5],cOs[5],rev[5]);
  
  //Initialize Underglow object
  totalLEDs = 0;
  for(int i=0;i<6;i++){
    totalLEDs+=lCounts[i];
  }
  ledArr = new CRGB[totalLEDs];
  
  //Run main LED initializer
  setupLEDs();
}
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

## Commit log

2020-11-13 Added LED patterns list
2020-12-19 Added in LED initialization. Now only supports WS2811 chipset and clones
2020-12-24 Setting menu expanded, little fixes
    [ArduinoIDETest.ino, UnderglowController.ino]
2020-12-25 More menus added, but menu untenable. Rework incoming.
    [ArduinoIDETest.ino]
2021-01-01 Rewrite stalled, for some reason changing 'selector' inside setMenu causes the program to think there's a passive function, even if there isn't. Need to check bounds.
    [MenuRestructure.ino]
2021-04-05 PCB design started
    [UnderglowPCB.kicad_pcb, UnderglowPCB.sch]
2021-04-06 PCB rev 1 schematic complete, custom footprint done.
    [UnderglowPCB.sch]
2021-04-09 Schemtic refined, removed screw terminals, added USB ESD prtection, test points, adjusted paths.
    [UnderglowPCB.csv]
2021-04-09 Version 1.0.0 of PCB is almost done. Need tooling holes and holds for DB9 mount.
    [UnderglowPCB.kicad_pcb, UnderglowPCB.sch]
2021-04-17 Minor PCB updates
    [UnderglowPCB.kicad_pcb]
2021-04-18 Posted to reddit, changes include TVS Zener diodes and new power solution. That's a lot bigger.
    [UnderglowPCB.kicad_pcb, UnderglowPCB.sch]
2021-05-22 Lastest draft of device
    [UnderglowPCB.kicad_pcb, UnderglowPCB.sch]
2021-05-24 PCB 1.2 finished. Needs some silkscreen work.
    [UnderglowPCB.kicad_pcb, UnderglowPCB.sch]
2021-05-24 PCB Ver 1.3.2 completed. Documentaion updated to reflect changes. BOM Added to Hardware.md
    [UnderglowPCB.csv, UnderglowPCB.kicad_pcb]
2021-05-26 PCB data updated, 1.3.2 ordering information is provided.
    [UnderglowPCB.csv, UnderglowPCB.kicad_pcb, UnderglowPCB.sch]
2021-05-26 Added position files, drill files, gerber files.
    [UnderglowPCB-B_Cu.gbr, UnderglowPCB-B_Mask.gbr, UnderglowPCB-B_Paste.gbr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]
2021-05-26 Updated Gerbers to remove x2, updated docs
    [UnderglowPCB-B_Cu.gbr, UnderglowPCB-B_Mask.gbr, UnderglowPCB-B_Paste.gbr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]
2021-05-29 Menu issue resolved, continue on.
    [MenuRestructure.ino]
2021-06-01 Passive items have switch to disangage selector.
2021-06-06 Refactored LED hardware functions in test code.
2021-06-06 New LED pattern test, built off of LED test. Currrently building structure
2021-07-01 Updated PCB to 1.3.4: silkscreen updates for cathode clarification. Test code moving along.
    [UnderglowPCB.kicad_pcb, UnderglowPCB.sch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]
2021-07-01 Continued fleshing out patterntest. Next is init of animations, updating of animations and basic patterns. need to test patterns initialize correctly.
    [LEDPatternTeset.ino]
2021-07-05 Patterns can be loaded to device. Animation backup array crashes device.
    [LEDPatternTeset.ino]
